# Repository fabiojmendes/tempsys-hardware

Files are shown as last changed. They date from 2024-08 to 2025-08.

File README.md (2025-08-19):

<!-- vim: set tw=80: -->

# Tempsys hardware

Kicad hardware design for the Tempsys board.

## Block diagram

Tempsys Block Diagram

## Schematics

The board is built around the
[E73-2G4M08S1C](https://www.cdebyte.com/products/E73-2G4M08S1C) module that
relies on the nRF52840 chip from Nordic. The hardware design is minimalistic to
avoid any unnecessary power draw.

In short:

- An external XTAL is used to further reduce power consumption.
- Pull-up resistors on the i2c bus.
- Programming headers are provided.
- Reset button.
- Extra GPIO headers if necessary.
- CR-2032 battery holder.

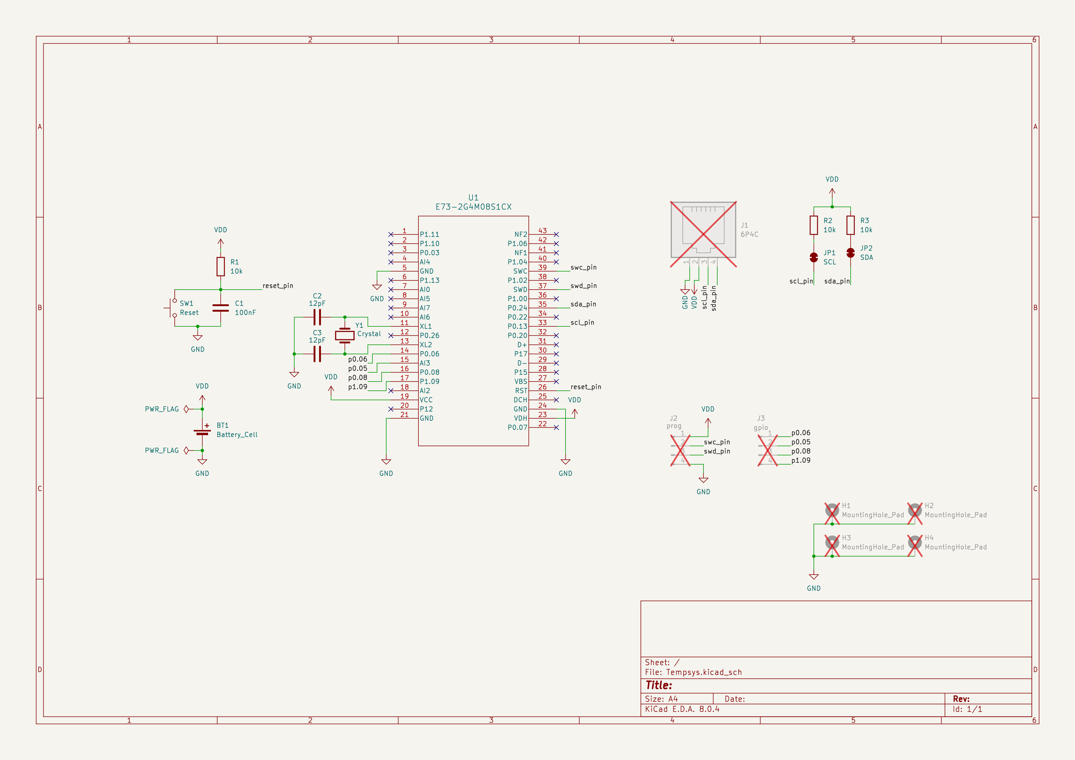
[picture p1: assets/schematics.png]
Schematics


## PCB

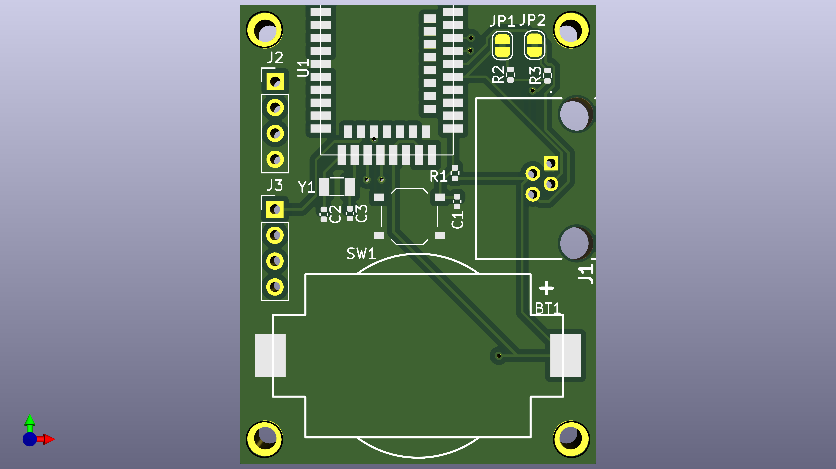
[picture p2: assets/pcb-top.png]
PCB Top
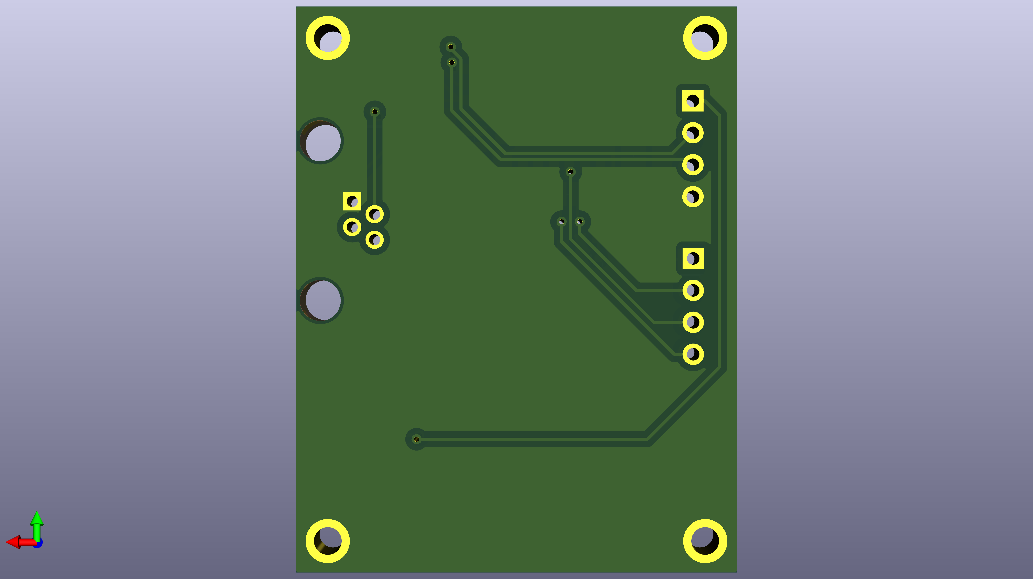
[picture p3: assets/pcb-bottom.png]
PCB Bottom
 

## Assembled product

Slightly older version of the PCB without the pull-up resistors.

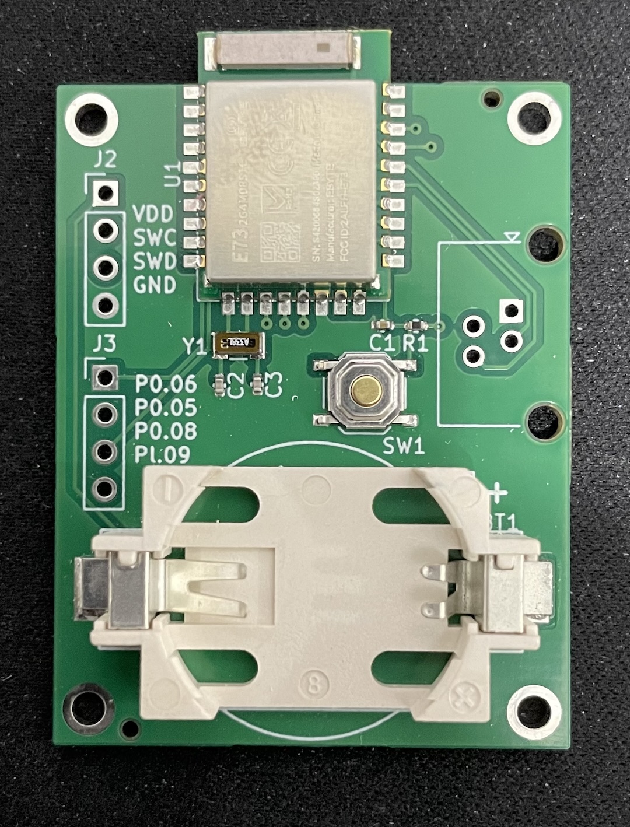
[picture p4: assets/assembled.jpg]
PCB Assembled


## Current draw

The hardware is optimized to sip as little power as possible. Thanks to the
Nordic low power capabilities this device runs for more than a year on a single
coin cell battery CR-2032. In idle it consumes only ~3uA, and around 250uA when
the Bluetooth radio is engaged.

From the [firmware](https://github.com/fabiojmendes/tempsys-firmware)
perspective, all devices are set to sleep when not in use and the advertising
rate for the Bluetooth LE is stretched as much as possible.

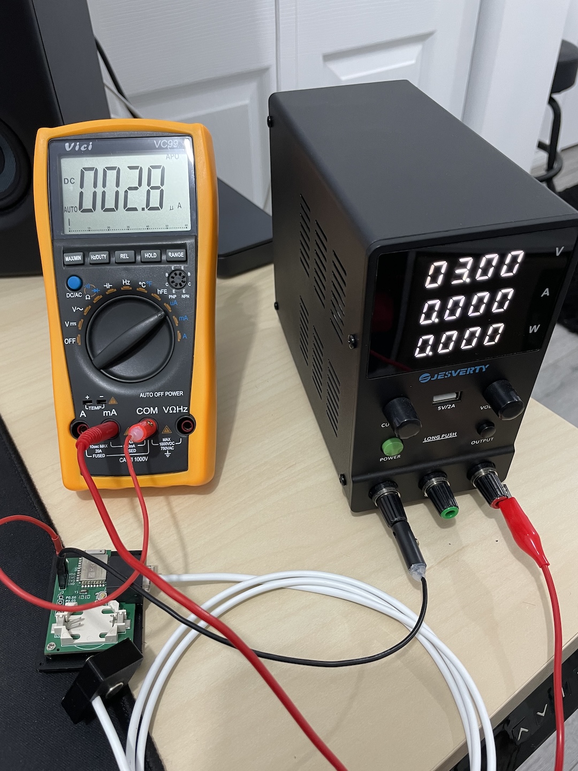
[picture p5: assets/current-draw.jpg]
Current Draw


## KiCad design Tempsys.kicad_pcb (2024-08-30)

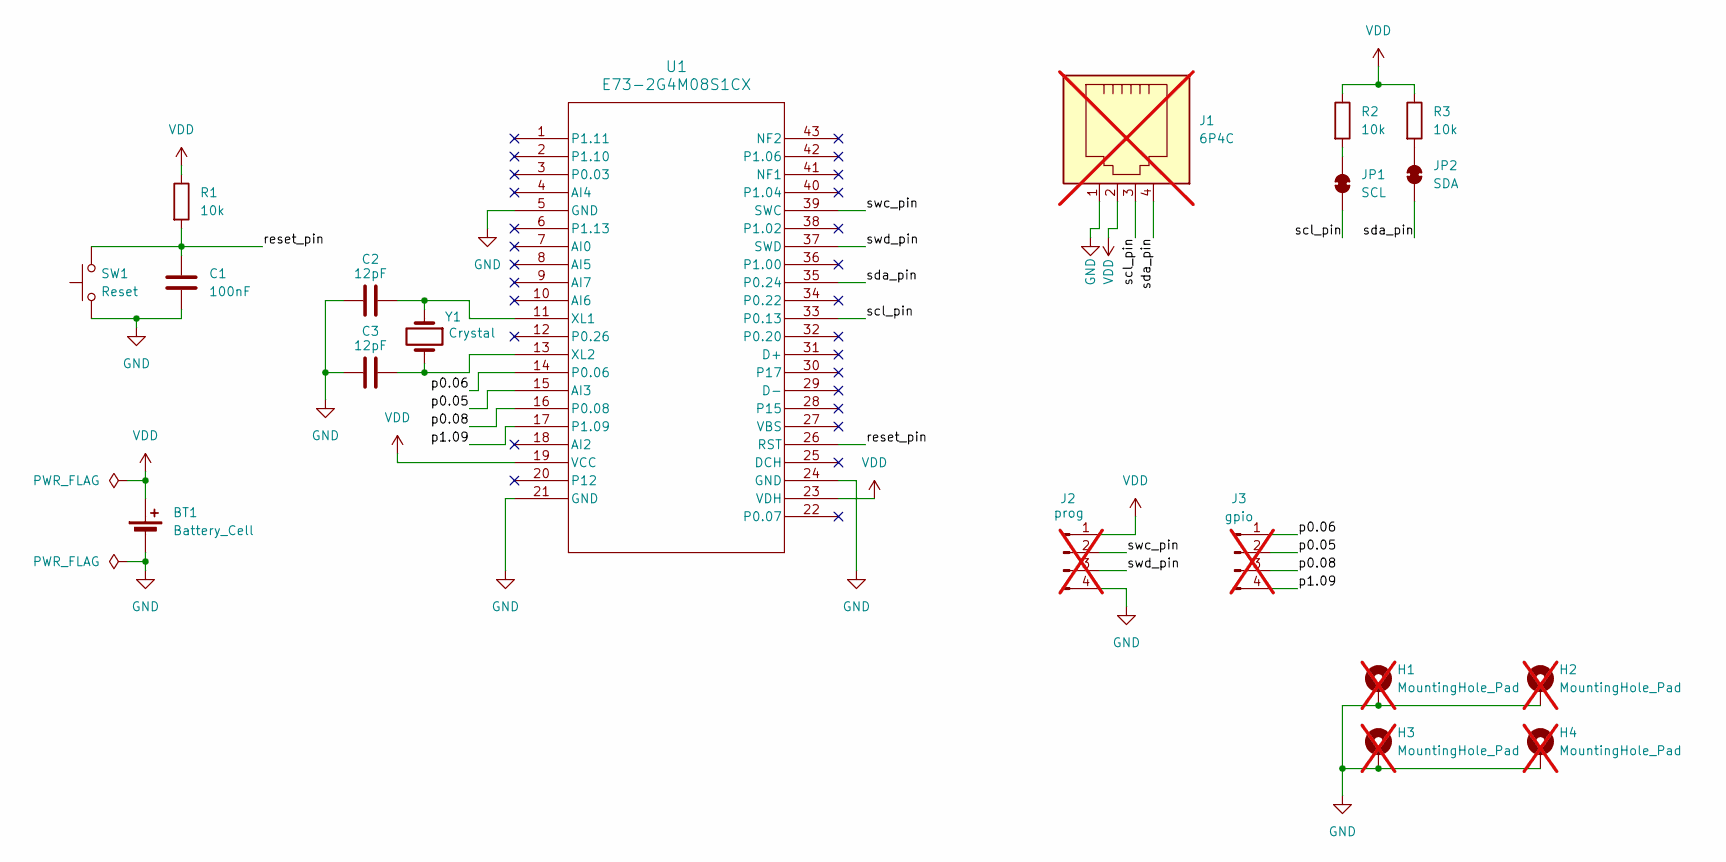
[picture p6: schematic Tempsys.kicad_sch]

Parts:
BT1: Battery_Cell; CR2032-BS-6-1; LCSC C70377
C1: 100nF; C_0402_1005Metric; LCSC C1525
C2, C3: 12pF; C_0402_1005Metric; LCSC C1547
H1, H2, H3, H4: MountingHole_Pad; MountingHole_2.2mm_M2_ISO7380_Pad; not fitted
J1: 6P4C; 438600003; LCSC C77856; not fitted
J2: prog; PinHeader_1x04_P2.54mm_Vertical; not fitted
J3: gpio; PinHeader_1x04_P2.54mm_Vertical; not fitted
JP1: SCL; SolderJumper-2_P1.3mm_Bridged_RoundedPad1.0x1.5mm
JP2: SDA; SolderJumper-2_P1.3mm_Bridged_RoundedPad1.0x1.5mm
R1, R2, R3: 10k; R_0402_1005Metric; LCSC C25744
SW1: Reset; SW_Push_1P1T_XKB_TS-1187A; LCSC C318884
U1: E73-2G4M08S1CX; E73(2G4M08S1C); LCSC C356849
Y1: Crystal; Crystal_SMD_3215-2Pin_3.2x1.5mm; LCSC C32346

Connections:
/p0.05: J3.2, U1.15 (AI3)
/p0.06: J3.1, U1.14 (P0.06)
/p0.08: J3.3, U1.16 (P0.08)
/p1.09: J3.4, U1.17 (P1.09)
/reset_pin: C1.1, R1.2, SW1.2, U1.26 (RST)
/scl_pin: J1.3, JP1.1 (A), U1.33 (P0.13)
/sda_pin: J1.4, JP2.1 (A), U1.35 (P0.24)
/swc_pin: J2.2, U1.39 (SWC)
/swd_pin: J2.3, U1.37 (SWD)
GND: BT1.2 (-), C1.2, C2.2, C3.2, H1.1, H2.1, H3.1, H4.1, J1.1, J2.4, SW1.1, U1.5 (GND), U1.21 (GND), U1.24 (GND)
unnamed: JP1.2 (B), R2.2
unnamed: JP2.2 (B), R3.2
unnamed: C2.1, U1.11 (XL1), Y1.1
unnamed: C3.1, U1.13 (XL2), Y1.2
VDD: BT1.1 (+), J1.2, J2.1, R1.1, R2.1, R3.1, U1.19 (VCC), U1.23 (VDH)

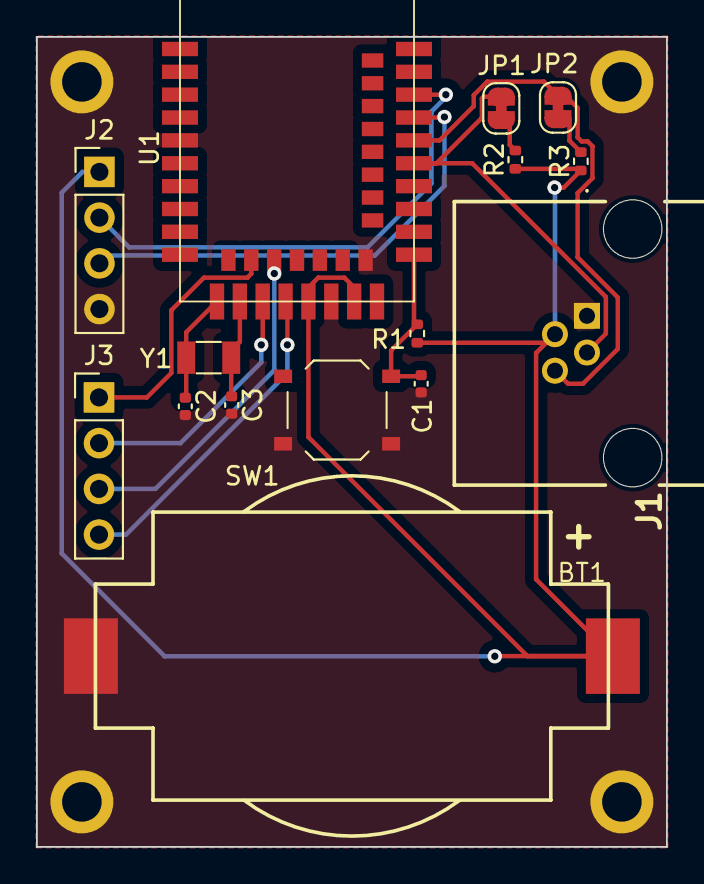
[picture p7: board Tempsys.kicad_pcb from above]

Board: 2 copper layers, 35.0 x 45.0 mm, 19 parts (0 on the bottom side), 15 nets.

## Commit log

2024-08-23 Adding molex connector 3d model
    [Tempsys.kicad_pcb]
2024-08-30 Adding pull-ups and jumpers. Also fixing the RJ11 footprint
    [Tempsys.kicad_pcb, Tempsys.kicad_sch]
